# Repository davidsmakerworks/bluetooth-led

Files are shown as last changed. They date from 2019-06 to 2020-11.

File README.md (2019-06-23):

# bluetooth-led
WS281x LED display driver controlled by Bluetooth (UART)

This is a driver for a string of WS281x (i.e., WS2811 or WS2812B) addressable RGB LEDs. It's designed for the PIC16F18325 using the CLC, SPI, and PWM peripherals to output the data stream in hardware. This significantly reduces CPU load. Updates are handled in the ISR at a rate of up to 60 times per second. At F<sub>osc</sub> = 32 Mhz (F<sub>cy</sub> = 8 MHz), the processing of these interrupts should use less than 0.5% of total CPU time.

A KiCad project is also included for a PCB that supports this driver code.

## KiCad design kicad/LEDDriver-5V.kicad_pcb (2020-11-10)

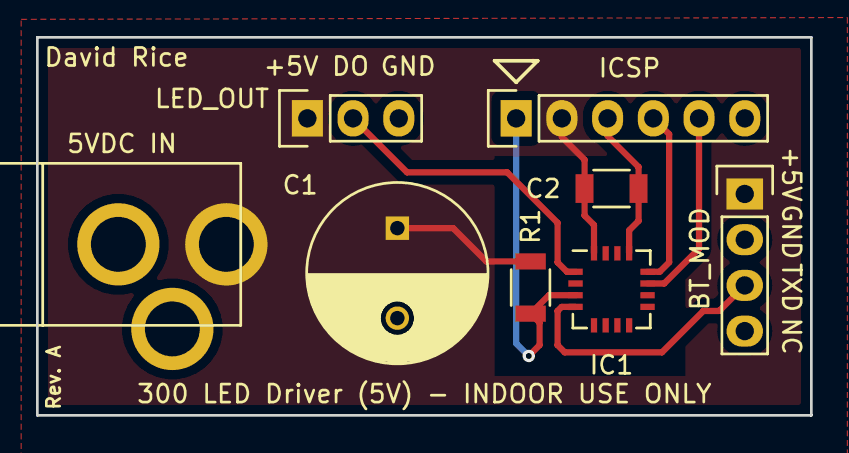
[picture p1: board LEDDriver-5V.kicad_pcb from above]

Board: 2 copper layers, 43.0 x 21.0 mm, 8 parts (0 on the bottom side), 7 nets.

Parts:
5VDC IN: BARREL_JACK
BT_MOD: BT_MOD; Pin_Header_Straight_1x04
C1: 1000uF; C_Radial_D10_L16_P5
C2: 0.1uf; C_1206
IC1: PIC16F18325-I/JQ; QFN-16-1EP_4x4mm_Pitch0.65mm
ICSP: ICSP; Pin_Header_Straight_1x06
LED_OUT: LED_OUT; Pin_Header_Straight_1x03
R1: 10K; R_1206

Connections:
+5V: 5VDC IN.1, BT_MOD.1, C1.1, C2.1, IC1.16, ICSP.2, LED_OUT.1, R1.2
GND: 5VDC IN.2, 5VDC IN.3, BT_MOD.2, C1.2, C2.2, IC1.13, ICSP.3, LED_OUT.3
unnamed: IC1.1, LED_OUT.2
unnamed: IC1.3, ICSP.1, R1.1
unnamed: BT_MOD.3, IC1.4
unnamed: IC1.11, ICSP.5
unnamed: IC1.12, ICSP.4

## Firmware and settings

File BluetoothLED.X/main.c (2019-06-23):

/*
 * Bluetooth LED Controller
 * Copyright (c) 2019 David Rice
 * 
 * Controls a string of WS281x LEDs with a Bluetooth (UART) interface to control various effects.
 * 
 * Supports up to 300 LEDs due to memory limitation of PIC16F18325.
 * 
 * Supports WS2811 in fast mode only.
 * 
 * Processor: PIC16F18325
 * 
 * Peripheral usage:
 * EUSART1 - Receives serial data from Bluetooth module
 * MSSP1 - Drives WS281x LED strip (SPI master mode) via CLC1
 * Timer1 - Generates system tick for processing LED strip updates
 * Timer2 - PWM clock source for WS281x protocol
 * PWM5 - Generates PWM signal for WS281x protocol
 * CLC1 - Combines MSSP1 and PWM5 signals to produce WS2812x protocol
 * 
 * Pin assignments:
 * RA5 - WS281x data output from CLC1
 * RC5 - EUSART1 data input from Bluetooth module
 * 
 * Version 3.3 - supports CLC with SPI in interrupt-driven transmission mode, refactored variable names, added TNET mode
 * Version 3.4 - corrected interrupt flag clearing code in ISR
 * Version 3.5 - refactored code to use C standard case
 *
 *
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
 * THE SOFTWARE IS PROVIDED "AS IS", WITHOUT WARRANTY OF ANY KIND, EXPRESS OR
 * IMPLIED, INCLUDING BUT NOT LIMITED TO THE WARRANTIES OF MERCHANTABILITY,
 * FITNESS FOR A PARTICULAR PURPOSE AND NONINFRINGEMENT. IN NO EVENT SHALL THE
 * AUTHORS OR COPYRIGHT HOLDERS BE LIABLE FOR ANY CLAIM, DAMAGES OR OTHER
 * LIABILITY, WHETHER IN AN ACTION OF CONTRACT, TORT OR OTHERWISE, ARISING FROM,
 * OUT OF OR IN CONNECTION WITH THE SOFTWARE OR THE USE OR OTHER DEALINGS IN THE
 * SOFTWARE.
 */

// PIC16F18325 Configuration Bit Settings

// 'C' source line config statements

// CONFIG1
#pragma config FEXTOSC = OFF    // FEXTOSC External Oscillator mode Selection bits (Oscillator not enabled)
#pragma config RSTOSC = HFINT32 // Power-up default value for COSC bits (HFINTOSC with 2x PLL (32MHz))
#pragma config CLKOUTEN = OFF   // Clock Out Enable bit (CLKOUT function is disabled; I/O or oscillator function on OSC2)
#pragma config CSWEN = ON       // Clock Switch Enable bit (Writing to NOSC and NDIV is allowed)
#pragma config FCMEN = OFF      // Fail-Safe Clock Monitor Enable (Fail-Safe Clock Monitor is disabled)

// CONFIG2
#pragma config MCLRE = ON       // Master Clear Enable bit (MCLR/VPP pin function is MCLR; Weak pull-up enabled)
#pragma config PWRTE = ON       // Power-up Timer Enable bit (PWRT enabled)
#pragma config WDTE = OFF       // Watchdog Timer Enable bits (WDT disabled; SWDTEN is ignored)
#pragma config LPBOREN = OFF    // Low-power BOR enable bit (ULPBOR disabled)
#pragma config BOREN = ON       // Brown-out Reset Enable bits (Brown-out Reset enabled, SBOREN bit ignored)
#pragma config BORV = LOW       // Brown-out Reset Voltage selection bit (Brown-out voltage (Vbor) set to 2.45V)
#pragma config PPS1WAY = ON     // PPSLOCK bit One-Way Set Enable bit (The PPSLOCK bit can be cleared and set only once; PPS registers remain locked after one clear/set cycle)
#pragma config STVREN = ON      // Stack Overflow/Underflow Reset Enable bit (Stack Overflow or Underflow will cause a Reset)
#pragma config DEBUG = OFF      // Debugger enable bit (Background debugger disabled)

// CONFIG3
#pragma config WRT = OFF        // User NVM self-write protection bits (Write protection off)
#pragma config LVP = ON         // Low Voltage Programming Enable bit (Low Voltage programming enabled. MCLR/VPP pin function is MCLR. MCLRE configuration bit is ignored.)

// CONFIG4
#pragma config CP = OFF         // User NVM Program Memory Code Protection bit (User NVM code protection disabled)
#pragma config CPD = OFF        // Data NVM Memory Code Protection bit (Data NVM code protection disabled)

// #pragma config statements should precede project file includes.
// Use project enums instead of #define for ON and OFF.

#include <xc.h>
#include <stdint.h>
#include <stdlib.h>
#include <stdbool.h>

/**** FREQUENTLY CHANGED CONFIGURATION VALUES START HERE ****/

/* Type of LEDs connected to driver - supported options are WS2811 and WS2812B */
#define WS2811

/* Maximum LED index connected to this driver (i.e., number of LEDs - 1) */
#define MAX_LED_INDEX 49

/* Initial modes */
#define INIT_MODE MODE_RND_ONE
#define INIT_LEVEL LEVEL_MID

/* Overall maximum values for various brightness levels
 * 
 * For strings or bright strips, usual values are 0xFF, 0x7F, 0x3F 
 * For small rings, usual values are 0x7F, 0x1F, 0x0F 
 */
#define MAX_BRIGHT 0x7F
#define MID_BRIGHT 0x1F
#define DIM_BRIGHT 0x0F

/* Maximums for secondary colors used in fire and ice effects 
 *
 * For strings or bright strips, usual values are 0x7F, 0x3F, 0x1F 
 * For small rings, usual values are 0x3F, 0x0F, 0x08 
 */
#define MAX_BRIGHT_SEC 0x3F
#define MID_BRIGHT_SEC 0x0F
#define DIM_BRIGHT_SEC 0x08

/**** FREQUENTLY CHANGED CONFIGURATION VALUES END HERE ****/

/* Frequency must be specified for delay loops */
#define _XTAL_FREQ 32000000

/* 
 * Baud Rate Generator value for 9600 baud at Fosc = 32MHz
 * 9600 baud: ((32000000 / 9600) / 64) - 1
 */
#define BAUD_RATE 51 

/* Define output pin for WS281x data stream */
#define LED_DATA_OUT LATAbits.LATA5

/* Define TRIS register for Bluetooth (UART) data */
#define UART_RX_TRIS TRISCbits.TRISC5

/* Define EEPROM addresses for random seed */
#define SEED_LOW_ADDR 0x7000
#define SEED_HIGH_ADDR 0x7001

/* 
 * Macros for putting color values at the appropriate index
 * Note that the WS2812B uses GRB format instead of RGB
 */
#ifdef WS2811
#define RED(x)   (x * 3)
#define GREEN(x) (x * 3) + 1
#define BLUE(x)  (x * 3) + 2
#else
#ifdef WS2812B
#define RED(x)   (x * 3) + 1
#define GREEN(x) (x * 3)
#define BLUE(x)  (x * 3) + 2
#else
#error LED controller type must be specified
#endif
#endif

/* Define available display modes */
typedef enum {
    MODE_STATIC = 0,
    MODE_INC,
    MODE_DEC,
    MODE_RND_ALL,
    MODE_RND_ONE,
    MODE_FIRE,
    MODE_ICE,
    MODE_SPARKS,
    MODE_XMAS,
    MODE_TNET
} DISP_MODE;

/* Define brightness levels */
typedef enum {
    LEVEL_DIM = 0,
    LEVEL_MID,
    LEVEL_BRIGHT
} DISP_LEVEL;

uint8_t color_data[(MAX_LED_INDEX + 1) * 3];

uint8_t brightness_val;
uint8_t secondary_val;

/* Data received from Bluetooth module via USART */
volatile uint8_t serial_data;

/* Flag to indicate if Bluetooth data was received in ISR */
volatile bool serial_pending = false;

/* Index of LED currently being updated by MSSP1 and CLC1 */
volatile uint16_t update_index = 0;

/* Flag to indicate if LED strip needs to be updated */
volatile bool update_needed = false;

/* ISR functions:
 * 
 * 1. Transmit LED data via MSSP1 and CLC1.
 * 2. Start update cycle if needed based on timer overflow.
 * 3. Process received data from EUSART1 (Bluetooth). 
 */
void __interrupt() isr(void) {
    /* Peripheral interrupts */
    if (INTCONbits.PEIE) {
        /* MSSP1 interrupt - fires when MSSP1 has finished sending SPI data */
        if (PIE1bits.SSP1IE && PIR1bits.SSP1IF) {
            PIR1bits.SSP1IF = 0;
            
            if (update_index <= ((MAX_LED_INDEX + 1) * 3)) {       
                SSP1BUF = color_data[update_index]; /* Transmit one byte - interrupt will fire again as soon as this byte is transmitted */
                update_index++;
            } else {               
                update_index = 0; /* If all data has been transmitted, set update_index to 0 to indicate that update is not running */
            }  
        }
        
        /* Timer1 interrupt - fires approximately 60 times per second */
        if (PIE1bits.TMR1IE && PIR1bits.TMR1IF) {
            PIR1bits.TMR1IF = 0;
            
            /* Only start update cycle if update is needed and update is not already in progress */
            if (update_needed && update_index == 0) {
                SSP1BUF = color_data[update_index]; /* Transmit first byte - subsequent bytes will be handled by MSSP1 interrupt */
                update_index++;
                update_needed = false;
            }
        }
        
        /* EUSART1 interrupt - fires when data has been received from Bluetooth module */
        if (PIE1bits.RCIE && PIR1bits.RCIF) {
            serial_data = RC1REG;
            serial_pending = true; /* Set flag so data can be processed in main loop */
        }
    }
}

/* 
 * Standard port initialization
 * Later functions will change some of these settings 
 */
void init_ports(void) {
    /* Disable all analog features */
    ANSELA = 0x00;
    ANSELC = 0x00;
    
    /* Set all ports to output */
    TRISA = 0x00;
    TRISC = 0x00;
    
    /* Pull all outputs low */
    LATA = 0x00;
    LATC = 0x00;
    
    /* Set TTL on RC5 due to 3.3V output from Bluteooth module */
    INLVLCbits.INLVLC5 = 0;
}

/* Initialize EUSART1 hardware registers */
void init_uart(void) {
    UART_RX_TRIS = 1; /* Set RX pin as input */
    
    RC1STAbits.CREN = 1; /* Continuous receive */
    TX1STAbits.SYNC = 0; /* Asynchronous */
    SP1BRG = BAUD_RATE; /* Baud rate as defined above */
    RC1STAbits.SPEN = 1; /* Enable serial port */
}

/* Initialize SPI module that will drive the CLC */
void init_spi(void) {
    /* SPI used only to drive CLC so no outputs defined */
    
    SSP1CON1bits.SSPM = 0b0011; /* Set SPI mode with CLK = T2_match/2 */
    SSP1CON1bits.SSPEN = 1; /* Enable MSSP */
}

/* Initialize Timer1 to drive display updates and Timer2 to be PWM clock source */
void init_timers(void) {
    T1CONbits.TMR1CS = 0b00; /* Timer1 source is Fosc/4 (instruction clock) */
    T1CONbits.T1CKPS = 0b10; /* Timer1 prescaler 1/4 = 2 MHz at 32 Mhz Fosc */
    T1CONbits.TMR1ON = 1; /* Enable Timer1 */
    
    PR2 = 4; /* 0.625 uSec at Fosc = 32 MHz */
    T2CONbits.TMR2ON = 1; /* Enable Timer2 */
}

/* Initialize PWM generator for WS281x zero-bit pulses */
void init_pwm(void) {
    PWM5DCH = 1;
    PWM5DCL = 0;
    
    PWM5CONbits.PWM5EN = 1; /* Enable PWM generator */
}

/* Set up CLC to output (SCK && SDO) || (nSDO && SCK && PWM) */
void init_clc(void) {
    RA5PPS = 0b00100; /* CLC1OUT on RA5 */
    
    CLC1SEL0bits.LC1D1S = 0b10011; /* CLC1 input 1 is SDO1 */
    CLC1SEL1bits.LC1D2S = 0b10010; /* CLC1 input 2 is SCK1 */
    CLC1SEL2bits.LC1D3S = 0b10000; /* CLC1 input 3 is PWM5OUT */
    
    CLC1GLS0 = 0x00;
    CLC1GLS1 = 0x00;
    CLC1GLS2 = 0x00;
    CLC1GLS3 = 0x00; /* Gate behavior is undefined at power-on so must be set to zero */
    
    CLC1GLS0bits.LC1G1D1T = 1; /* SDO input to AND gate 1 */
    
    CLC1GLS1bits.LC1G2D2T = 1; /* SCK input to AND gate 1 */
    
    /* nSDO && SCK = n(SDO || nSCK) */
    CLC1GLS2bits.LC1G3D1T = 1;
    CLC1GLS2bits.LC1G3D2N = 1; /* SDO || nSCK input to AND gate 2 */
    
    CLC1GLS3bits.LC1G4D3T = 1; /* PWM5OUT input to AND gate 2 */
    
    CLC1POL = 0x00; /* Clear all inversion bits */
    CLC1POLbits.LC1G3POL = 1; /* Gate 3 n(SDO || nSCK) is inverted to obtain (nSDO && SDK) */
    
    CLC1CONbits.LC1EN = 1; /* Enable CLC1 */
}

/* Sets brightness variables based on selected brightness value */
void set_brightness(DISP_LEVEL brt) {
    switch (brt) {
        case LEVEL_DIM:
            brightness_val = DIM_BRIGHT;
            secondary_val = DIM_BRIGHT_SEC;
            break;
        case LEVEL_MID:
            brightness_val = MID_BRIGHT;
            secondary_val = MID_BRIGHT_SEC;
            break;
        case LEVEL_BRIGHT:
            brightness_val = MAX_BRIGHT;
            secondary_val = MAX_BRIGHT_SEC;
            break;
        default:
            break;
    }
}

/* Sets all LEDs to a given RGB value */
void set_all(uint8_t red, uint8_t green, uint8_t blue) {
    uint16_t current_led;
    
    for (current_led = 0; current_led <= MAX_LED_INDEX; current_led++) {
        color_data[RED(current_led)] = red;
        color_data[GREEN(current_led)] = green;
        color_data[BLUE(current_led)] = blue;
    }
}

/* Sets all LEDs to random RGB values with maximums specified in parameters */
void random_all(uint8_t max_red, uint8_t max_green, uint8_t max_blue) {
    uint16_t current_led;
    
    for (current_led = 0; current_led <= MAX_LED_INDEX; current_led++) {
        color_data[RED(current_led)] = (max_red == 0) ? 0 : (rand() % max_red);
        color_data[GREEN(current_led)] = (max_green == 0) ? 0 : (rand() % max_green);
        color_data[BLUE(current_led)] = (max_blue == 0) ? 0 : (rand() % max_blue);
    }
}

/* Sets one random LED to a random RGB value with maximums specified in parameters */
void random_one(uint8_t max_red, uint8_t max_green, uint8_t max_blue) {
    uint16_t current_led;
    
    current_led = rand() % (MAX_LED_INDEX + 1);
    
    color_data[RED(current_led)] = (max_red == 0) ? 0 : (rand() % max_red);
    color_data[GREEN(current_led)] = (max_green == 0) ? 0 : (rand() % max_green);
    color_data[BLUE(current_led)] = (max_blue == 0) ? 0 : (rand() % max_blue);
}

/* Sets one random LED to either red or green */
void random_one_xmas(uint8_t brightness) {
    uint16_t current_led;
    
    current_led = rand() % (MAX_LED_INDEX + 1);
    
    if ((rand() % 100) > 50) {
        color_data[RED(current_led)] = brightness;
        color_data[GREEN(current_led)] = 0;
        color_data[BLUE(current_led)] = 0;
    } else {
        color_data[RED(current_led)] = 0;
        color_data[GREEN(current_led)] = brightness;
        color_data[BLUE(current_led)] = 0;
    }
}

/* Sets one random LED to either white, green, or blue */
void random_one_tnet(uint8_t brightness) {
    uint16_t current_led;
    uint8_t rand_val;
    
    current_led = rand() % (MAX_LED_INDEX + 1);
    rand_val = rand() % 100;
    
    if (rand_val > 66) {
        color_data[RED(current_led)] = brightness;
        color_data[GREEN(current_led)] = brightness;
        color_data[BLUE(current_led)] = brightness;
    } else if (rand_val > 33) {
        color_data[RED(current_led)] = 0;
        color_data[GREEN(current_led)] = brightness;
        color_data[BLUE(current_led)] = 0;
    } else {
        color_data[RED(current_led)] = 0;
        color_data[GREEN(current_led)] = 0;
        color_data[BLUE(current_led)] = brightness;
    }
}

/* Fire effect */
void random_fire(uint8_t red, uint8_t max_green) {
    uint16_t current_led;
    
    current_led = rand() % (MAX_LED_INDEX + 1);
    
    color_data[RED(current_led)] = red;
    color_data[GREEN(current_led)] = (max_green == 0) ? 0 : (rand() % max_green);
    color_data[BLUE(current_led)] = 0;
}

/* Ice effect */
void random_ice(uint8_t max_red_green, uint8_t blue) {
    uint16_t current_led;
    uint8_t red_green;
    
    current_led = rand() % (MAX_LED_INDEX + 1);
    red_green = (max_red_green == 0) ? 0 : (rand() % max_red_green);
    
    color_data[RED(current_led)] = red_green;
    color_data[GREEN(current_led)] = red_green;
    color_data[BLUE(current_led)] = blue;
}

/* Retrieves a random number generator seed from EEPROM and stores an updated seed for next power-on */
void seed_random(void) {
    uint16_t seed;
    
    NVMCON1bits.NVMREGS = 1; /* Set NV module to access EEPROM */ 
    
    NVMADR = SEED_LOW_ADDR;
    NVMCON1bits.RD = 1;
    seed = NVMDATL; /* Read low byte of seed from EEPROM */
    
    NVMADR = SEED_HIGH_ADDR;
    NVMCON1bits.RD = 1;
    seed = seed | (NVMDATL << 8); /* Read high byte of seed from EEPROM */
    
    srand(seed); /* Seed random number generator with stored seed */
    
    seed = rand();
    
    NVMCON1bits.NVMREGS = 1;
    NVMCON1bits.WREN = 1; /* Enable EEPROM writes */
    
    NVMADR = SEED_LOW_ADDR;
    NVMDATL = (uint8_t)seed;
    NVMCON2 = 0x55;
    NVMCON2 = 0xAA;
    NVMCON1bits.WR = 1; /* Write low byte of seed to EEPROM */
    
    NVMADR = SEED_HIGH_ADDR;
    NVMDATL = (uint8_t)(seed >> 8);
    NVMCON2 = 0x55;
    NVMCON2 = 0xAA;
    NVMCON1bits.WR = 1; /* Write high byte of seed to EEPROM */
    
    NVMCON1bits.WREN = 0; /* Disable EEPROM writes */
}
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

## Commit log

2019-06-23 Update folder name
    [LEDDriver-5V.kicad_pcb, LEDDriver-5V.sch]
2020-11-10 Update info block, update for KiCad 5.1.7
    [LEDDriver-5V.kicad_pcb]
